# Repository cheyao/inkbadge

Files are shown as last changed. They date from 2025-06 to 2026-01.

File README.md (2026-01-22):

# Undercity + Github badges

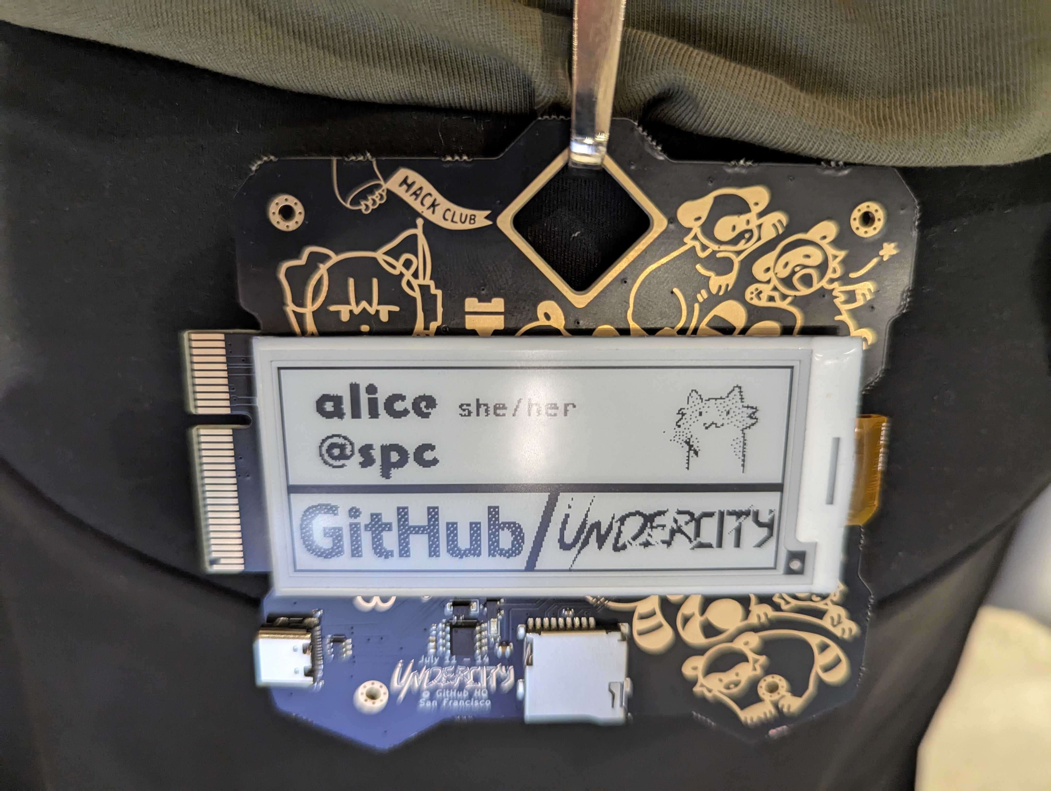
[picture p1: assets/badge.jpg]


Official badges for undercity (Hackathon @ Github HQ, https://highway.hackclub.com/)

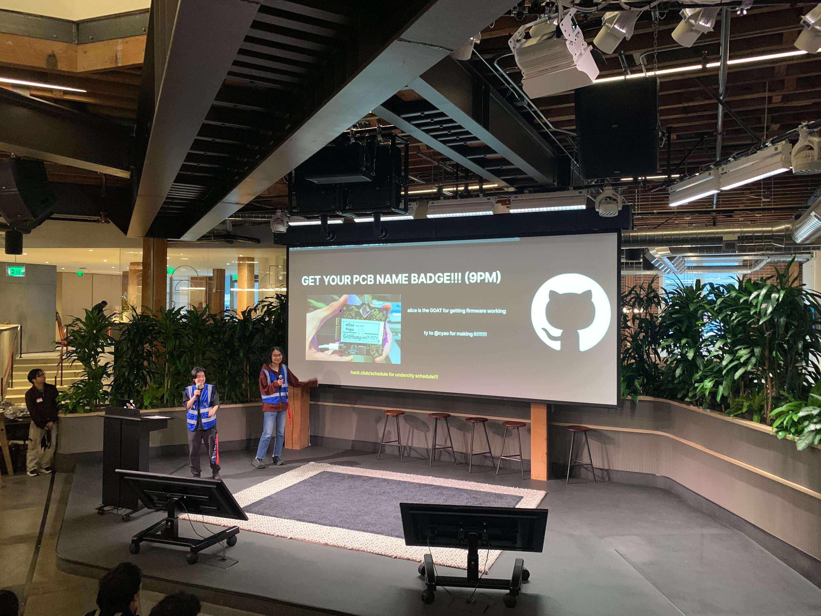
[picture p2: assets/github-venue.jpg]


Find the firmware [here](https://github.com/espcaa/undercity-lanyard)! (Start made by me, finished by spc & mpk :D)

Specs:
- 4x User buttons
- RP2350A
- Big big flash
- Super cool pcie connector
- Working firmware 
- Onboard eink module
- 6 neopixels go flash flash
- Pretty art by bnuuuuyguy!
- Awesome artline by acon (@acornitum)
- Check out pcb online [here](https://kicanvas.org/?github=https%3A%2F%2Fgithub.com%2Fcheyao%2Finkbadge%2Ftree%2Fmain%2Fhardware%2Finkbadge)

Additional battery mode avaliable! (Explosions not included this time)

Solder a lipo onto the central holes on top of the buttons - left is V+ right is GND

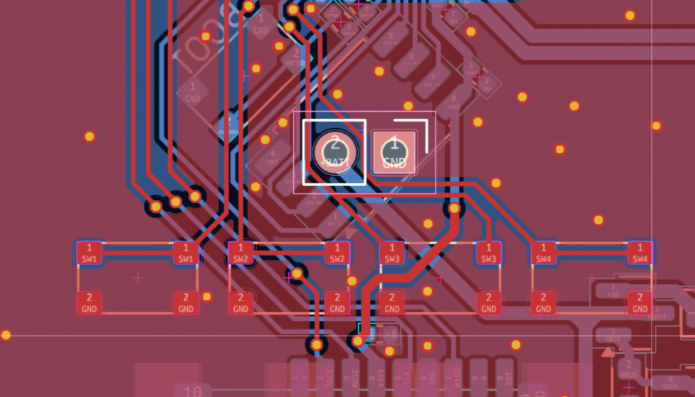
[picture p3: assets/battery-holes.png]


Licensed under Solderpad license

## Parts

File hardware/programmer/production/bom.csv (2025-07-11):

Designator | Footprint | Quantity | Value | LCSC Part #
C1, C19, C5 | 0603 | 3 | 10u | C19702
C10, C6, C7 | 0402 | 3 | 4.7u | C23733
C11, C12, C13, C14, C15, C16, C17, C18, C2, C8 | 0402 | 10 | 100n | C1525
C3, C4 | 0402 | 2 | 15p | C1548
C40 | 0402 | 1 | 4.7uF | C23733
J1 | SDCardlcsc | 1 | Micro_SD_Card | C5454948
J2 | USB_C_Receptacle_GCT_USB4105-xx-A_16P_TopMnt_Horizontal | 1 | USB_C_Receptacle_USB2.0_14P | C2765186
J3 | PCIe_x4_Edgeboard_Connector | 1 | Bus_PCI_Express_x4 | C2832353
L1 | L_pol_2016 | 1 | 3.3u | C42411119
R1 | 0402 | 1 | 10k | C25744
R16 | 0402 | 1 | 33 | C25105
R2, R4, R6 | 0402 | 3 | 1k | C11702
R3, R5 | 0402 | 2 | 5.1k | C25905
R7, R8 | 0402 | 2 | 27 | C25105
SW1, SW2 | SW_Push_SPST_TSA016 | 2 | SW_Push | C2888430
U1 | QFN-60-1EP_7x7mm_P0.4mm_EP3.4x3.4mm_ThermalVias | 1 | ~ | C42411118
U2 | SOT-223-3_TabPin2 | 1 | NCP1117-3.3_SOT223 | C6186
U3 | SOT-23-6 | 1 | SRV05-4 | C85364
U5 | SOIC-8_5.3x5.3mm_P1.27mm | 1 | W25Q128JVS | C97521
Y1 | Crystal_SMD_3225-4Pin_3.2x2.5mm | 1 | 12MHz 10pf | C20625731

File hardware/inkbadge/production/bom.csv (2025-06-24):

Designator | Footprint | Quantity | Value | LCSC Part #
C1, C19, C28, C5, C9 | 0603 | 5 | 10uF | C19702
C10, C6, C7 | 0402 | 3 | 4.7uF | C23733
C11, C12, C13, C14, C15, C16, C17, C18, C2, C22, C32, C33, C34, C35, C36, C8 | 0402 | 16 | 100nF | C1525
C20, C21, C23, C24, C25, C26, C30, C31, C37, C38 | 0402 | 10 | 1uF | C52923
C27, C29, C39 | 0603 | 3 | 4.7uF | C69335
C3, C4 | 0402 | 2 | 15pF | C1548
C40 | 0402 | 1 | 4.7uF | C1548
D1, D11, D2, D3 | D_SOD-123 | 4 | MBR0530 | C5204746
D10, D5, D6, D7, D8, D9 | LED_WS2812B-2020_PLCC4_2.0x2.0mm | 6 | WS2812B-2020 | C5349955
D4 | 0603 | 1 | LED | C2286
J1 | SDCardlcsc | 1 | Micro_SD_Card | C5454948
J3 | USB_C_Receptacle_GCT_USB4105-xx-A_16P_TopMnt_Horizontal | 1 | USB_C_Receptacle_USB2.0_14P | C2765186
L1 | L_pol_2016 | 1 | 3.3u | C42411119
L2 | L_APV_ANR4018 | 1 | 10uH 1A | C167808
Q2 | SOT-23 | 1 | AO3401A | C15127
Q3 | SOT-23 | 1 | IRLML2060 | C5122027
R1, R13 | 0402 | 2 | 10k | C25744
R10, R14 | 0402 | 2 | 1.5k | C25867
R11, R15 | 0402 | 2 | 470 | C25117
R12 | 0402 | 1 | 0.47 | C3017627
R16 | 0402 | 1 | 33 | C25105
R2, R4, R6 | 0402 | 3 | 1k | C11702
R3, R5, R9 | 0402 | 3 | 5.1k | C25905
R7, R8 | 0402 | 2 | 27 | C25105
SW1, SW2, SW3, SW4, SW5, SW6 | SW_Push_SPST_TSA016 | 6 | SW_Push | C2888430
U1 | QFN-60-1EP_7x7mm_P0.4mm_EP3.4x3.4mm_ThermalVias | 1 | RP2350A | C42411118
U2 | SOT-223-3_TabPin2 | 1 | NCP1117-3.3_SOT223 | C6186
U3 | SOT-23-6 | 1 | SRV05-4 | C85364
U4 | LCSC_1x24-1MP_P0.5mm_Horizontal | 1 | Conn | C262567
U5 | SOIC-8_5.3x5.3mm_P1.27mm | 1 | W25Q128JVS | C97521
U6 | SOP-8_3.9x4.9mm_P1.27mm-TP | 1 | TP4056-42-ESOP8 | C16581
Y1 | Crystal_SMD_3225-4Pin_3.2x2.5mm | 1 | 12MHz 10pf | C20625731

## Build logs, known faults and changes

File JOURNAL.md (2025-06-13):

# 30/05/25

Copied the base rp2350a schematic, and decided on the screen:



https://item.taobao.com/item.htm?id=673989348784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{%22aplus_abtest%22%3A%22d8240614a409935e88e0eb0ca016da3a%22}&xxc=taobaoSearch

- 1.5h

----------

# 31/05/25

Made a basic connector pinout, chinese stuff got bad docs lol.



- 1.5h

----------

Yay after some searching I found an adafruit example schematic:



- 1h

----------

Finished most of the schematic!!!



- 1h

----------

# 01/06/25

Layed out the connector side of the PCB! acon ghosted me tho :skulk: 



- 0.5h

----------

# 03/06/25

And here's the current progress!



- 1h

----------

# 05/06/25

Forgot to journal yesterday, but this is what I got today

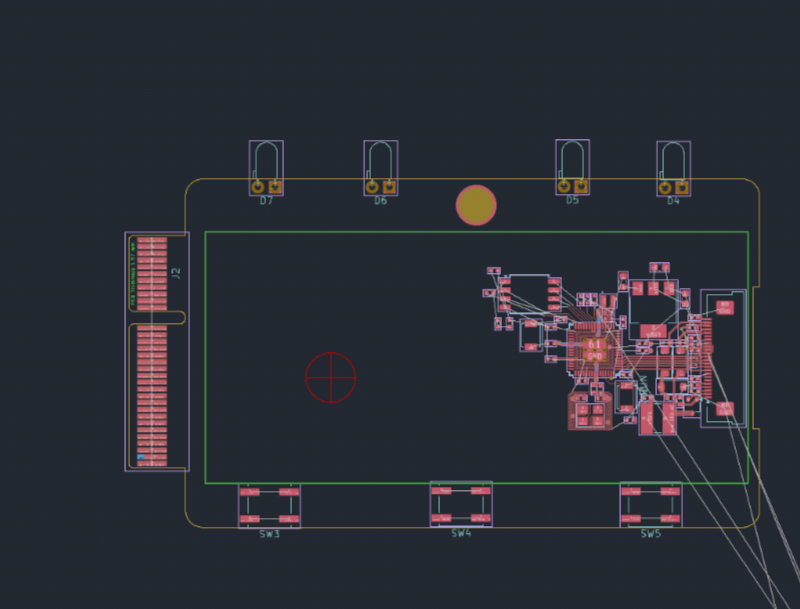
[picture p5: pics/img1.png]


- 1h

----------

# 06/06/25

Made the rough outline w/acon, looks pretty good!

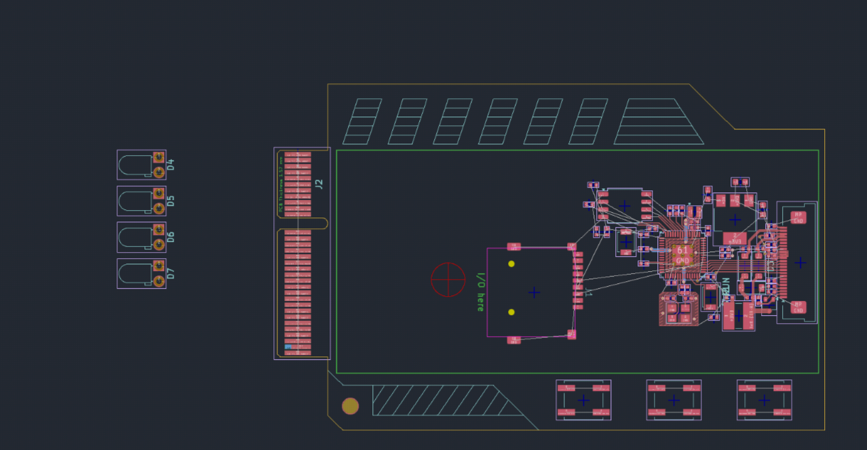
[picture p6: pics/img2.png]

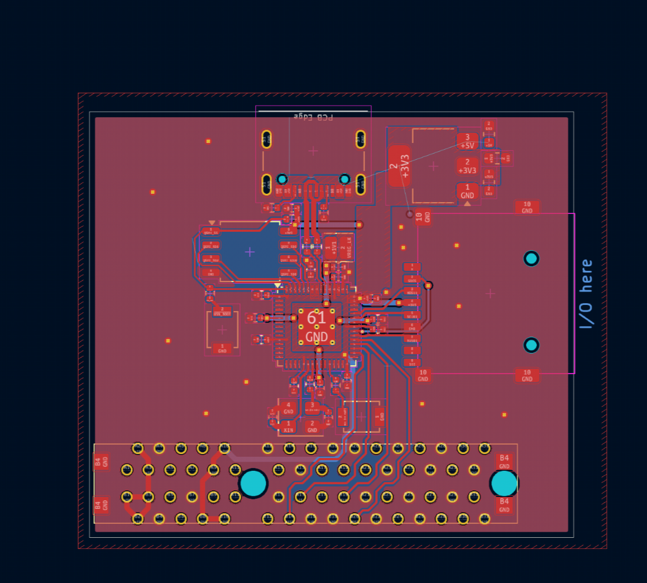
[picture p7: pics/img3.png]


- 1.5h

----------

# 08-09/06/25

And the programmer is done!

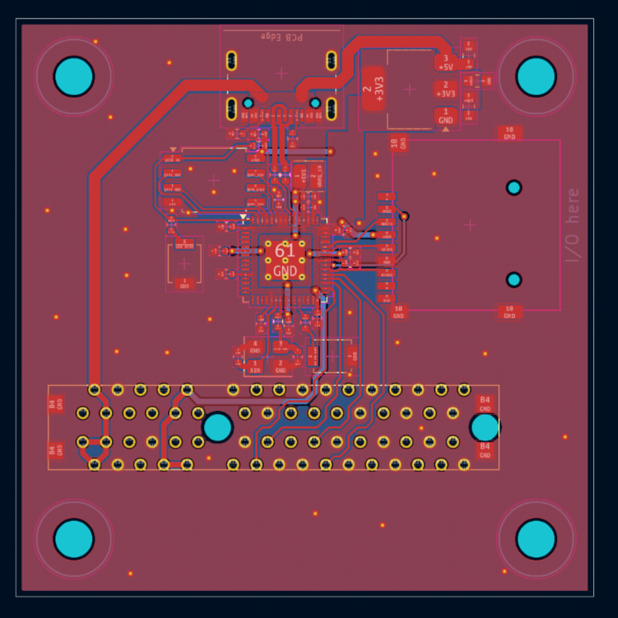
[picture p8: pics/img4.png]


- 4h

----------

# 11/06/25

Finished the programmer!

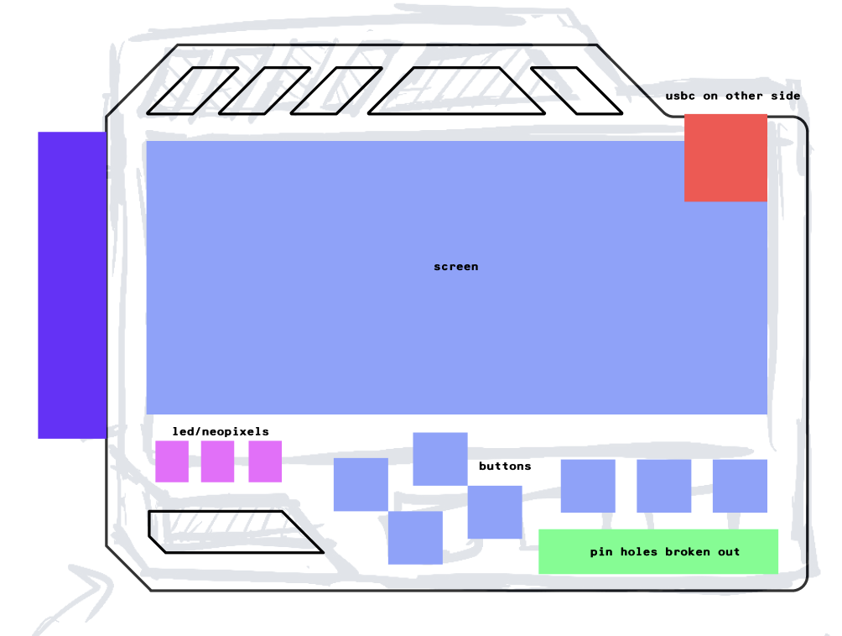
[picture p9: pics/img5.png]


- 1h

----------

# 13/06/25

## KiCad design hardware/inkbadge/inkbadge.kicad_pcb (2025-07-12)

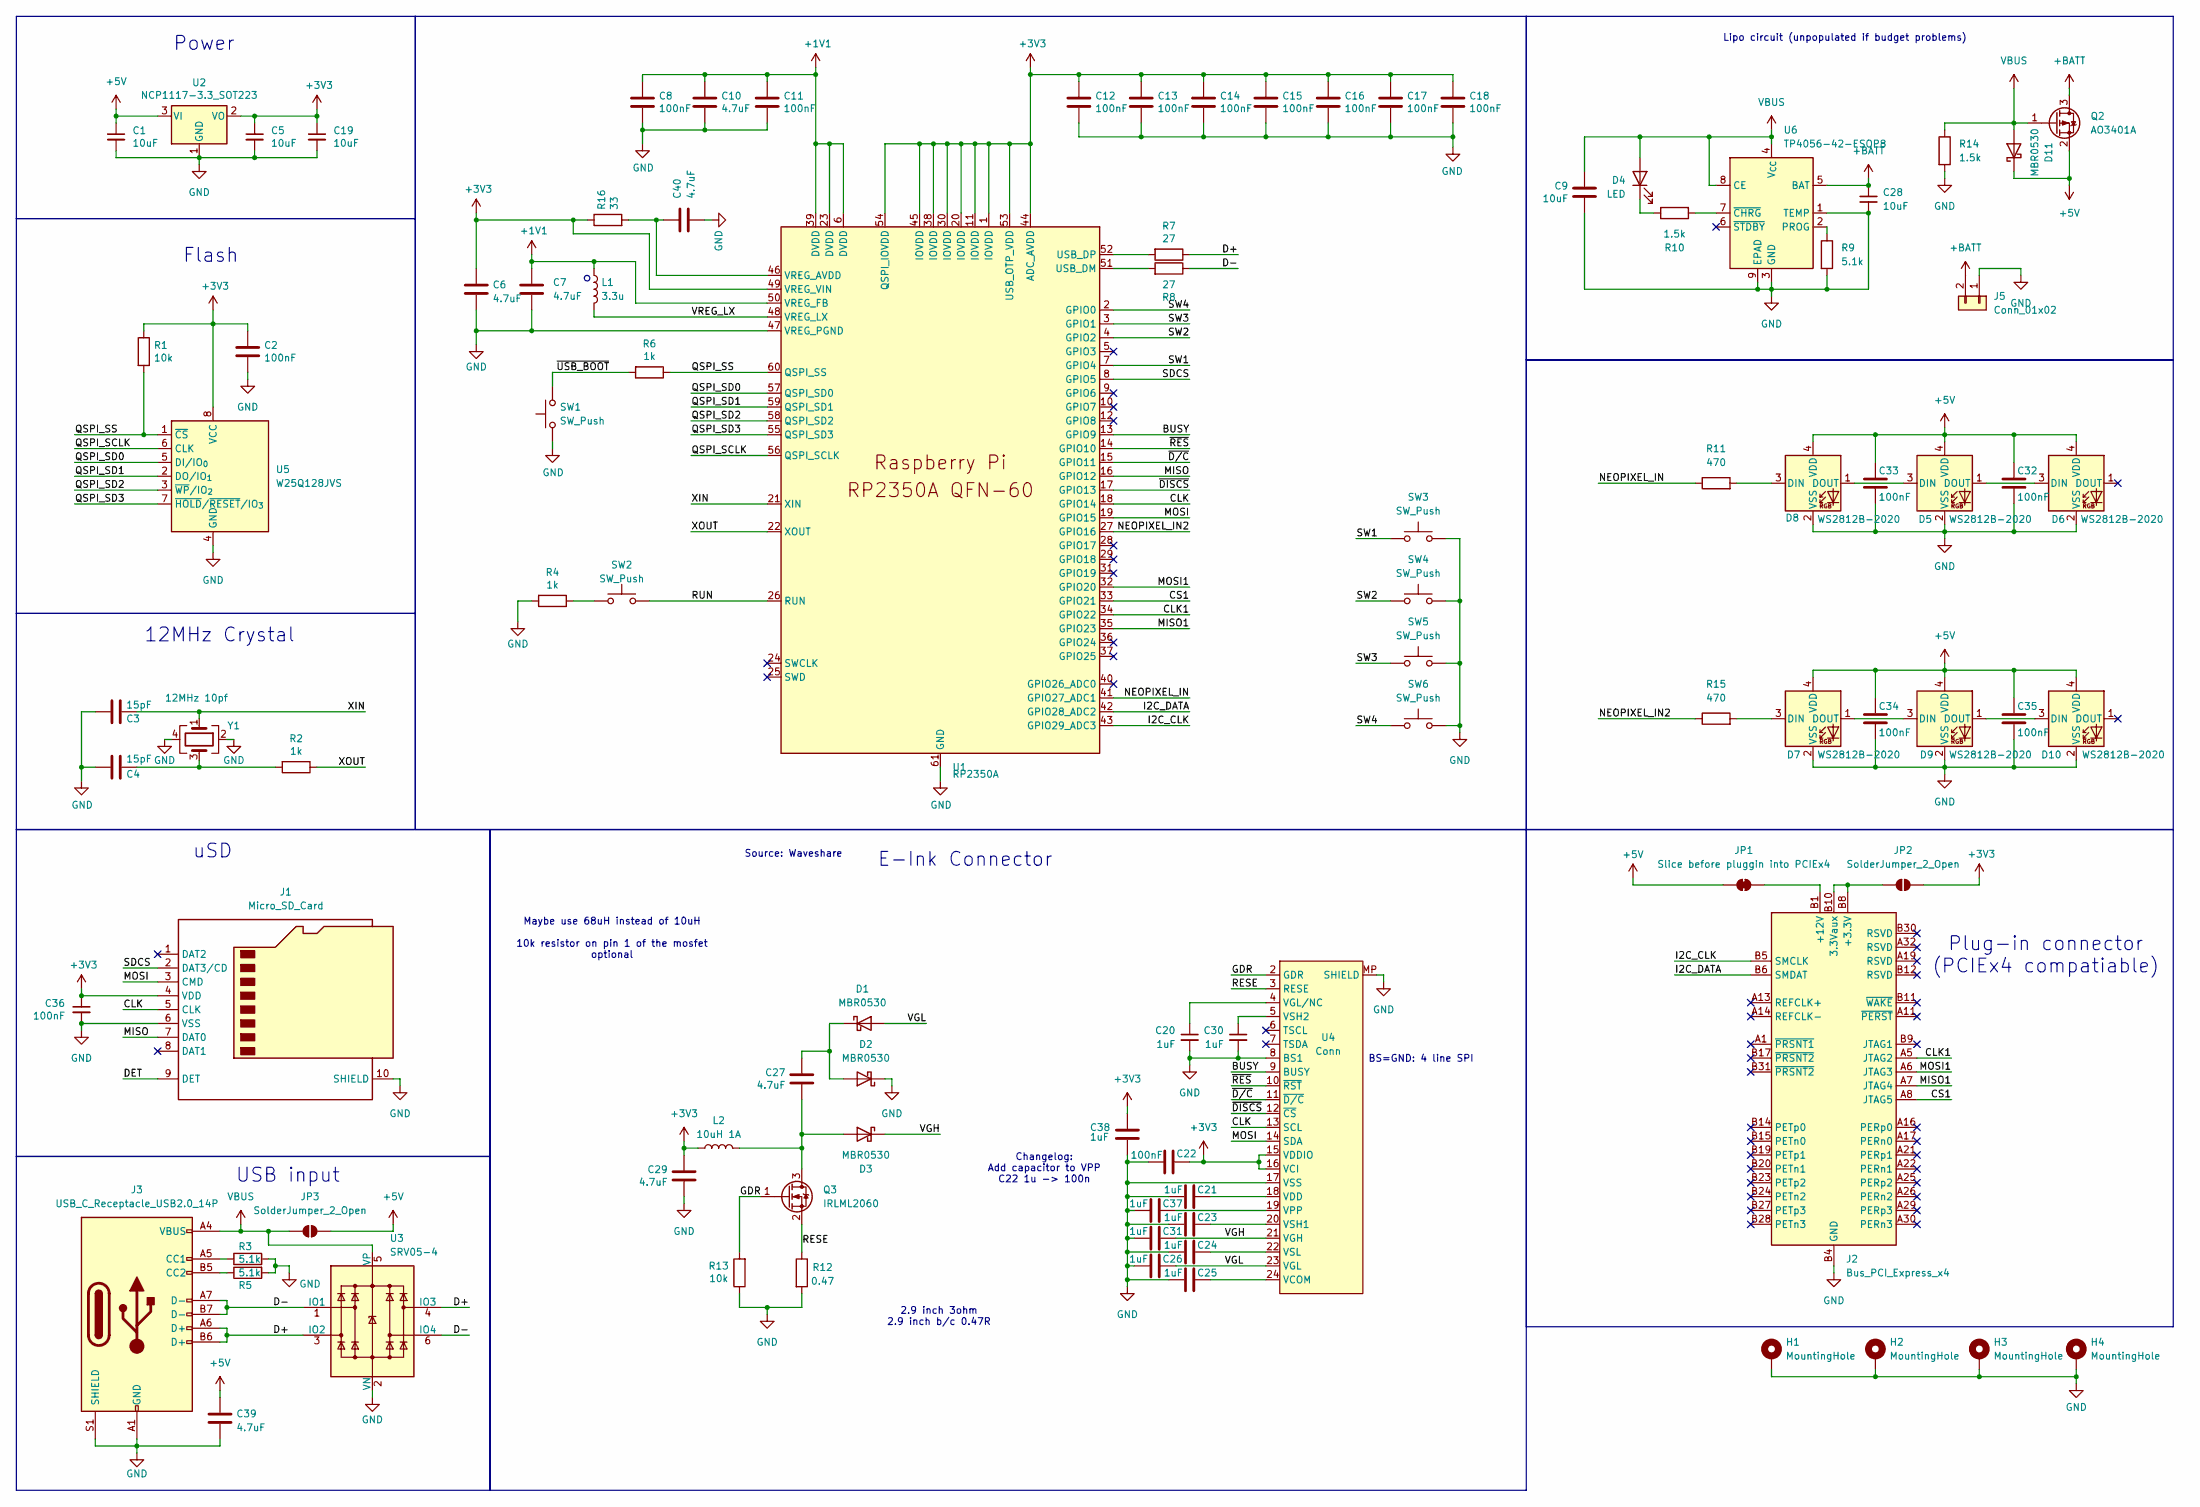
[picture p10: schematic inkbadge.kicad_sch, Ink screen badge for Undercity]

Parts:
C1, C5, C9, C19, C28: 10uF; C_0603_1608Metric; LCSC Part # C19702
C2, C8, C11, C12, C13, C14, C15, C16, C17, C18, C22, C32, C33, C34, C35, C36: 100nF; C_0402_1005Metric; LCSC Part # C1525
C3, C4: 15pF; C_0402_1005Metric; LCSC Part # C1548
C6, C7, C10, C40: 4.7uF; C_0402_1005Metric; LCSC Part # C23733
C20, C21, C23, C24, C25, C26, C30, C31, C37, C38: 1uF; C_0402_1005Metric; LCSC Part # C52923
C27, C29, C39: 4.7uF; C_0603_1608Metric; LCSC Part # C69335
D1, D2, D3, D11: MBR0530; D_SOD-123; LCSC Part # C5204746
D4: LED; LED_0603_1608Metric; LCSC Part # C2286
D5, D6, D7, D8, D9, D10: WS2812B-2020; LED_WS2812B-2020_PLCC4_2.0x2.0mm; LCSC Part # C5349955
H1, H2, H3, H4: MountingHole; MountingHole_2.2mm_M2_Pad_Via
J1: Micro_SD_Card; SDCardlcsc; LCSC Part # C5454948
J2: Bus_PCI_Express_x4; BUS_PCIexpress_x4
J3: USB_C_Receptacle_USB2.0_14P; USB_C_Receptacle_GCT_USB4105-xx-A_16P_TopMnt_Horizontal; LCSC Part # C2765186
J5: Conn_01x02; PinHeader_1x02_P2.54mm_Vertical
JP1: Slice before pluggin into PCIEx4; SolderJumper-2_P1.3mm_Bridged_RoundedPad1.0x1.5mm
JP2, JP3: SolderJumper_2_Open; SolderJumper-2_P1.3mm_Open_RoundedPad1.0x1.5mm
L1: 3.3u; L_pol_2016; LCSC Part # C42411119
L2: 10uH 1A; L_APV_ANR4018; LCSC Part # C167808
Q2: AO3401A; SOT-23; LCSC Part # C15127
Q3: IRLML2060; SOT-23; LCSC Part # C5122027
R1, R13: 10k; R_0402_1005Metric; LCSC Part # C25744
R2, R4, R6: 1k; R_0402_1005Metric; LCSC Part # C11702
R3, R5, R9: 5.1k; R_0402_1005Metric; LCSC Part # C25905
R7, R8: 27; R_0402_1005Metric; LCSC Part # C25105
R10, R14: 1.5k; R_0402_1005Metric; LCSC Part # C25867
R11, R15: 470; R_0402_1005Metric; LCSC Part # C25117
R12: 0.47; R_0402_1005Metric; LCSC Part # C3017627
R16: 33; R_0402_1005Metric; LCSC Part # C25105
SW1, SW2, SW3, SW4, SW5, SW6: SW_Push; SW_Push_SPST_TSA016; LCSC Part # C2888430
U1: RP2350A; QFN-60-1EP_7x7mm_P0.4mm_EP3.4x3.4mm_ThermalVias; LCSC Part # C42411118
U2: NCP1117-3.3_SOT223; SOT-223-3_TabPin2; LCSC Part # C6186
U3: SRV05-4; SOT-23-6; LCSC Part # C85364
U4: Conn; LCSC_1x24-1MP_P0.5mm_Horizontal; LCSC Part # C262567
U5: W25Q128JVS; SOIC-8_5.3x5.3mm_P1.27mm; LCSC Part # C97521
U6: TP4056-42-ESOP8; SOP-8_3.9x4.9mm_P1.27mm-TP; LCSC Part # C16581
Y1: 12MHz 10pf; Crystal_SMD_3225-4Pin_3.2x2.5mm; LCSC Part # C20625731

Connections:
+1V1: C7.1, C8.1, C10.1, C11.1, L1.1, U1.6 (DVDD), U1.23 (DVDD), U1.39 (DVDD), U1.50 (VREG_FB)
+3V3: C2.1, C5.1, C6.1, C12.1, C13.1, C14.1, C15.1, C16.1, C17.1, C18.1, C19.1, C22.1, C29.1, C36.1, C38.1, J1.4 (VDD), JP2.2 (B), L2.1, R1.1, R16.1, U1.1 (IOVDD), U1.11 (IOVDD), U1.20 (IOVDD), U1.30 (IOVDD), U1.38 (IOVDD), U1.44 (ADC_AVDD), U1.45 (IOVDD), U1.49 (VREG_VIN), U1.53 (USB_OTP_VDD), U1.54 (QSPI_IOVDD), U2.2 (VO), U4.15 (VDDIO), U4.16 (VCI), U5.8 (VCC)
+5V: C1.1, C32.1, C33.1, C34.1, C35.1, C39.1, D5.4 (VDD), D6.4 (VDD), D7.4 (VDD), D8.4 (VDD), D9.4 (VDD), D10.4 (VDD), D11.1 (K), JP1.1 (A), JP3.2 (B), Q2.2 (S), U2.3 (VI)
+BATT: C28.1, J5.2, Q2.3 (D), U6.5 (BAT)
/BUSY: U1.13 (GPIO9), U4.9 (BUSY)
/CLK: J1.5 (CLK), U1.18 (GPIO14), U4.13 (SCL)
/CLK1: J2.A5 (JTAG2), U1.34 (GPIO22)
/CS1: J2.A8 (JTAG5), U1.33 (GPIO21)
/D+: J3.A6 (D+), J3.B6 (D+), R7.1, U3.3 (IO2), U3.4 (IO3)
/D-: J3.A7 (D-), J3.B7 (D-), R8.1, U3.1 (IO1), U3.6 (IO4)
/DET: J1.9 (DET)
/GDR: Q3.1 (G), R13.2, U4.2 (GDR)
/I2C_CLK: J2.B5 (SMCLK), U1.43 (GPIO29_ADC3)
/I2C_DATA: J2.B6 (SMDAT), U1.42 (GPIO28_ADC2)
/MISO: J1.7 (DAT0), U1.16 (GPIO12)
/MISO1: J2.A7 (JTAG4), U1.35 (GPIO23)
/MOSI: J1.3 (CMD), U1.19 (GPIO15), U4.14 (SDA)
/MOSI1: J2.A6 (JTAG3), U1.32 (GPIO20)
/NEOPIXEL_IN: R11.1, U1.41 (GPIO27_ADC1)
/NEOPIXEL_IN2: R15.1, U1.27 (GPIO16)
/QSPI_SCLK: U1.56 (QSPI_SCLK), U5.6 (CLK)
/QSPI_SD0: U1.57 (QSPI_SD0), U5.5 (DI/IO_{0})
/QSPI_SD1: U1.59 (QSPI_SD1), U5.2 (DO/IO_{1})
/QSPI_SD2: U1.58 (QSPI_SD2), U5.3 (~WP/IO_{2})
/QSPI_SD3: U1.55 (QSPI_SD3), U5.7 (~HOLD/~RESET/IO_{3})
/QSPI_SS: R1.2, R6.1, U1.60 (QSPI_SS), U5.1 (~CS)
/RESE: Q3.2 (S), R12.1, U4.3 (RESE)
/RUN: SW2.2, U1.26 (RUN)
/SDCS: J1.2 (DAT3/CD), U1.8 (GPIO5)
/SW1: SW3.1, U1.7 (GPIO4)
/SW2: SW4.1, U1.4 (GPIO2)
/SW3: SW5.1, U1.3 (GPIO1)
/SW4: SW6.1, U1.2 (GPIO0)
/VGH: C31.1, D3.1 (K), U4.21 (VGH)
/VGL: C26.1, D1.2 (A), U4.23 (VGL)
/VREG_LX: L1.2, U1.48 (VREG_LX)
/XIN: C3.1, U1.21 (XIN), Y1.1
/XOUT: R2.1, U1.22 (XOUT)
/~DISCS: U1.17 (GPIO13), U4.12 (~CS)
/~D/C: U1.15 (GPIO11), U4.11 (~D/C)
/~RES: U1.14 (GPIO10), U4.10 (~RST)
/~USB_BOOT: R6.2, SW1.2
GND: C1.2, C2.2, C3.2, C4.2, C5.2, C6.2, C7.2, C8.2, C9.2, C10.2, C11.2, C12.2, C13.2, C14.2, C15.2, C16.2, C17.2, C18.2, C19.2, C20.2, C21.2, C22.2, C23.2, C24.2, C25.2, C26.2, C28.2, C29.2, C30.2, C31.2, C32.2, C33.2, C34.2, C35.2, C36.2, C37.2, C38.2, C39.2, C40.2, D2.1 (K), D5.2 (VSS), D6.2 (VSS), D7.2 (VSS), D8.2 (VSS), D9.2 (VSS), D10.2 (VSS), H1.1, H2.1, H3.1, H4.1, J1.6 (VSS), J1.10 (SHIELD), J2.A4 (GND), J2.A12 (GND), J2.A15 (GND), J2.A18 (GND), J2.A20 (GND), J2.A23 (GND), J2.A24 (GND), J2.A27 (GND), J2.A28 (GND), J2.A31 (GND), J2.B4 (GND), J2.B7 (GND), J2.B13 (GND), J2.B16 (GND), J2.B18 (GND), J2.B21 (GND), J2.B22 (GND), J2.B25 (GND), J2.B26 (GND), J2.B29 (GND), J2.B32 (GND), J3.A1 (GND), J3.A12 (GND), J3.B1 (GND), J3.B12 (GND), J3.S1 (SHIELD), J5.1, R3.2, R4.2, R5.2, R9.2, R12.2, R13.1, R14.2, SW1.1, SW3.2, SW4.2, SW5.2, SW6.2, U1.47 (VREG_PGND), U1.61 (GND), U2.1 (GND), U3.2 (VN), U4.8 (BS1), U4.17 (VSS), U4.MP (SHIELD), U5.4 (GND), U6.1 (TEMP), U6.3 (GND), U6.9 (EPAD), Y1.2, Y1.4
unnamed: C4.1, R2.2, Y1.3
unnamed: C27.1, D1.1 (K), D2.2 (A)
unnamed: C27.2, D3.2 (A), L2.2, Q3.3 (D)
unnamed: D4.1 (K), R10.1
unnamed: D5.3 (DIN), D8.1 (DOUT)
unnamed: D5.1 (DOUT), D6.3 (DIN)
unnamed: D7.3 (DIN), R15.2
unnamed: D7.1 (DOUT), D9.3 (DIN)
unnamed: D8.3 (DIN), R11.2
unnamed: D9.1 (DOUT), D10.3 (DIN)
unnamed: J2.A9 (+3.3V), J2.A10 (+3.3V), J2.B8 (+3.3V), J2.B10 (3.3Vaux), JP2.1 (A)
unnamed: J3.A5 (CC1), R3.1
unnamed: J3.B5 (CC2), R5.1
unnamed: J2.A2 (+12V), J2.A3 (+12V), J2.B1 (+12V), J2.B2 (+12V), J2.B3 (+12V), JP1.2 (B)
unnamed: R4.1, SW2.1
unnamed: R8.2, U1.51 (USB_DM)
unnamed: R7.2, U1.52 (USB_DP)
unnamed: C40.1, R16.2, U1.46 (VREG_AVDD)
unnamed: C25.1, U4.24 (VCOM)
unnamed: C21.1, U4.18 (VDD)
unnamed: C20.1, U4.4 (VGL/NC)
unnamed: C37.1, U4.19 (VPP)
unnamed: C23.1, U4.20 (VSH1)
unnamed: C30.1, U4.5 (VSH2)
unnamed: C24.1, U4.22 (VSL)
unnamed: R9.1, U6.2 (PROG)
unnamed: R10.2, U6.7 (~CHRG)
VBUS: C9.1, D4.2 (A), D11.2 (A), J3.A4 (VBUS), J3.A9 (VBUS), J3.B4 (VBUS), J3.B9 (VBUS), JP3.1 (A), Q2.1 (G), R14.1, U3.5 (VP), U6.4 (V_{CC}), U6.8 (CE)

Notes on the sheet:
USB input
Maybe use 68uH instead of 10uH 10k resistor on pin 1 of the mosfet optional
Plug-in connector (PCIEx4 compatiable)
Changelog: Add capacitor to VPP C22 1u -> 100n
Lipo circuit (unpopulated if budget problems)
Flash
2.9 inch 3ohm 2.9 inch b/c 0.47R
BS=GND: 4 line SPI
uSD
Source: Waveshare
12MHz Crystal
Power
E-Ink Connector

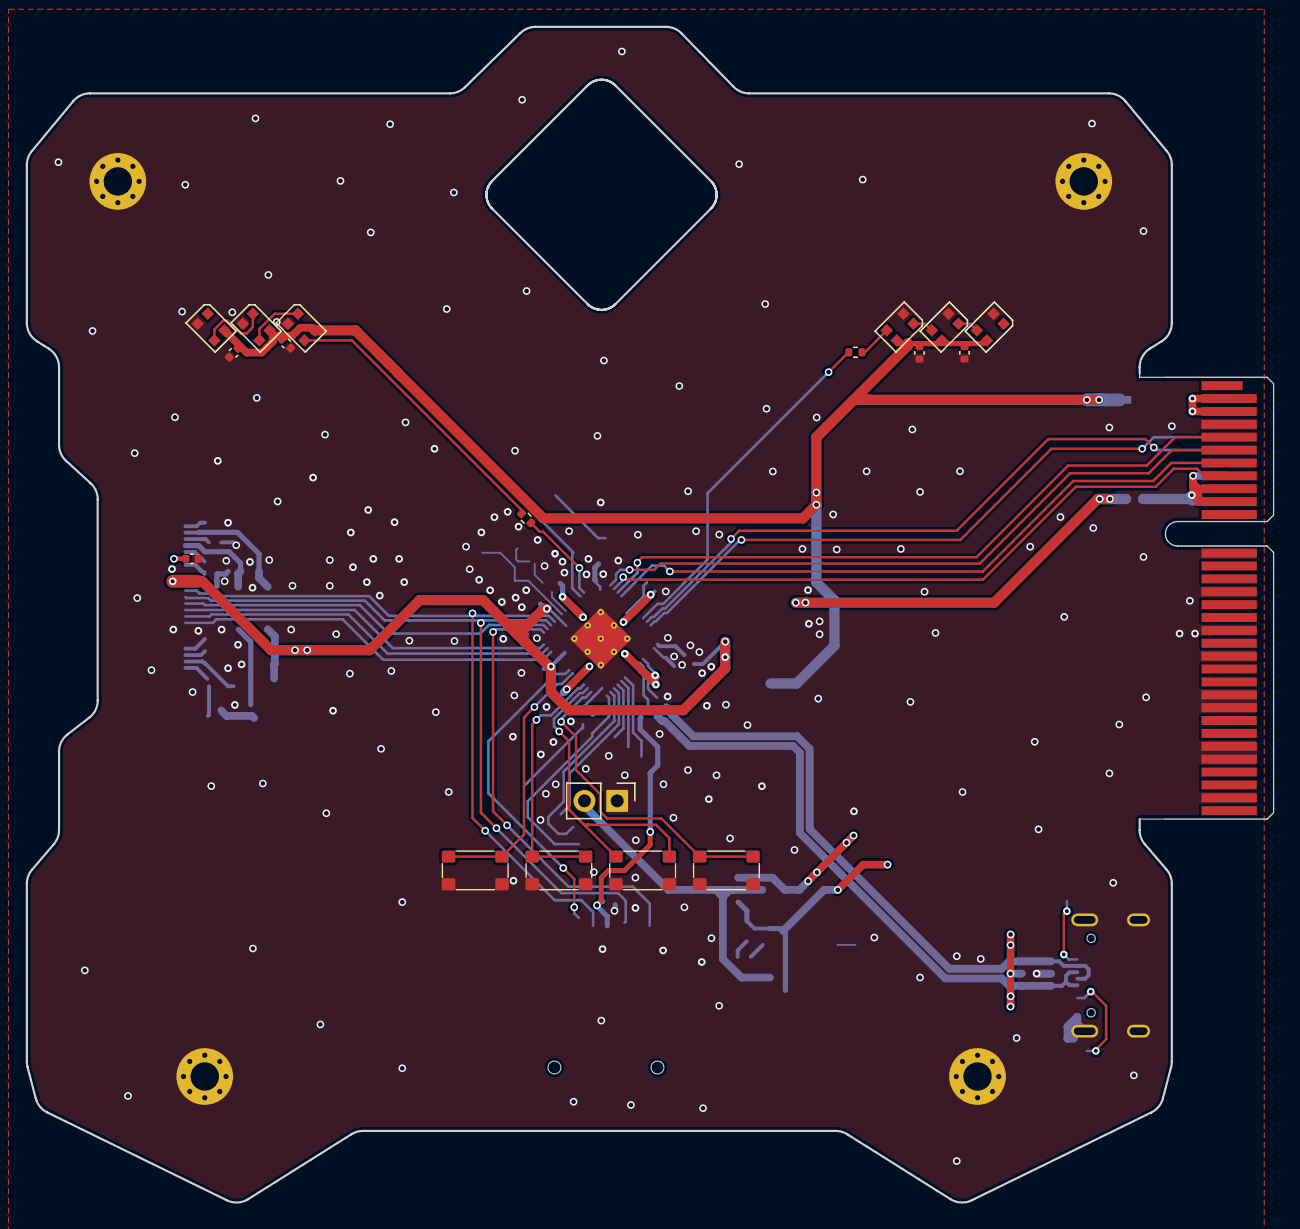
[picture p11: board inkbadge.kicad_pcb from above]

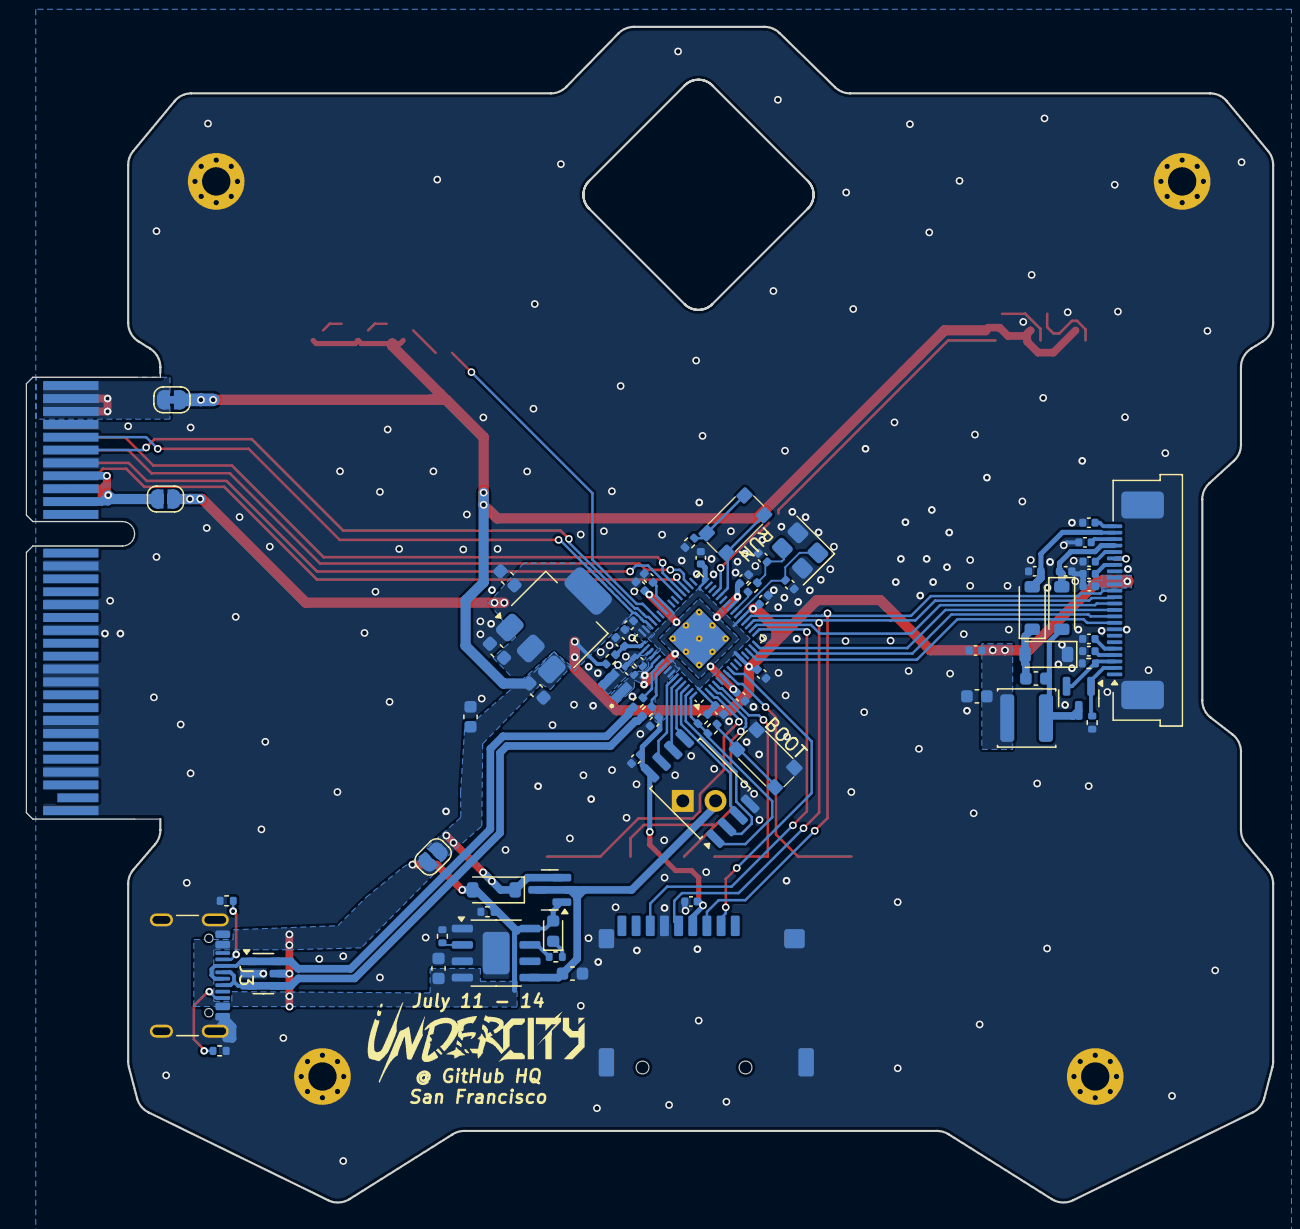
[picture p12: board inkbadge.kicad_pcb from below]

Board: 2 copper layers, 96.8 x 91.3 mm, 95 parts (73 on the bottom side), 70 nets.

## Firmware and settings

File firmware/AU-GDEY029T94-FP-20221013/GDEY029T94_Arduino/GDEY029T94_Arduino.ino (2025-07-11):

#include <SPI.h>
#include"Ap_29demo.h"
//IO settings
int BUSY_Pin = 9; 
int RES_Pin = 10; 
int DC_Pin = 11; 
int CS_Pin = 13; 

#define EPD_W21_CS_0 digitalWrite(CS_Pin,LOW)
#define EPD_W21_CS_1 digitalWrite(CS_Pin,HIGH)
#define EPD_W21_DC_0  digitalWrite(DC_Pin,LOW)
#define EPD_W21_DC_1  digitalWrite(DC_Pin,HIGH)
#define EPD_W21_RST_0 digitalWrite(RES_Pin,LOW)
#define EPD_W21_RST_1 digitalWrite(RES_Pin,HIGH)
#define isEPD_W21_BUSY digitalRead(BUSY_Pin)

////////FUNCTION//////
   
void SPI_Write(unsigned char value);
void Epaper_Write_Command(unsigned char command);
void Epaper_Write_Data(unsigned char command);
//EPD
void Epaper_HW_SW_RESET(void);
void EPD_HW_Init(void); //Electronic paper initialization
void EPD_Update(void);

void EPD_Part_Init(void);//Local refresh initialization
void EPD_Part_Update(void); 

void EPD_WhiteScreen_White(void);
void EPD_DeepSleep(void);
//Display 
void EPD_WhiteScreen_ALL(const unsigned char *datas);
void EPD_SetRAMValue_BaseMap(const unsigned char * datas);
void EPD_Dis_Part(unsigned int x_start,unsigned int y_start,const unsigned char * datas,unsigned int PART_COLUMN,unsigned int PART_LINE);
void EPD_Dis_Part_myself(unsigned int x_startA,unsigned int y_startA,const unsigned char * datasA,
                         unsigned int x_startB,unsigned int y_startB,const unsigned char * datasB,
                         unsigned int x_startC,unsigned int y_startC,const unsigned char * datasC,
                         unsigned int x_startD,unsigned int y_startD,const unsigned char * datasD,
                         unsigned int x_startE,unsigned int y_startE,const unsigned char * datasE,
                         unsigned int PART_COLUMN,unsigned int PART_LINE
                        );
void EPD_HW_Init_Fast(void);
void EPD_WhiteScreen_ALL_Fast(const unsigned char *datas);
//Display canvas function
void EPD_HW_Init_GUI(void); //EPD init GUI
void EPD_Display(unsigned char *Image); 
void EPD_HW_Init_P(void);
void EPD_Standby(void);

void EPD_HW_Init_Fast(void);
void EPD_WhiteScreen_ALL_Fast(const unsigned char *datas);
constexpr const int _MISO_EPD = 12;  // AKA SPI RX (same as SD MISO)

SPISettings spisettings(1000000, MSBFIRST, SPI_MODE0);
constexpr const int _MOSI_EPD = 15;  // AKA SPI TX (same as SD MOSI)
constexpr const int _CS_EPD = 13;
constexpr const int _SCK_EPD = 14;   // AKA SPI SCK (same as SD SCK)
void setup() {
  SPI1.setMISO(_MISO_EPD);
  SPI1.setMOSI(_MOSI_EPD);
  SPI1.setSCK(_SCK_EPD);
  SPI1.setCS(_CS_EPD);
   pinMode(BUSY_Pin, INPUT); 
   pinMode(RES_Pin, OUTPUT);  
   pinMode(DC_Pin, OUTPUT);    
   pinMode(CS_Pin, OUTPUT);   
   //SPI
   SPI1.beginTransaction(SPISettings(10000000, MSBFIRST, SPI_MODE0)); 
   SPI1.begin ();  
}
////////Partial refresh schematic////////////////

/////Y/// (0,0)               /---/(x,y)
          //                 /---/
          //                /---/  
          //x
          //
          //
//Tips//
/*When the electronic paper is refreshed in full screen, the picture flicker is a normal phenomenon, and the main function is to clear the display afterimage in the previous picture.
  When the local refresh is performed, the screen does not flash.*/
/*When you need to transplant the driver, you only need to change the corresponding IO. The BUSY pin is the input mode and the others are the output mode. */
  
void loop() {
    unsigned char fen_L,fen_H,miao_L,miao_H; 

    /************Fast picture display(1.5s)*******************/
    EPD_HW_Init_Fast(); //EPD init Fast
    EPD_WhiteScreen_ALL_Fast(gImage_1);//EPD_picture1
    EPD_DeepSleep();//EPD_DeepSleep,Sleep instruction is necessary, please do not delete!!!
    delay(2000); //2s  
    
    while(1); 
  ////////////////////////////////////////////////////////////////////////  
      //Clean
    // Clear:
    // delay(2000);
    // EPD_HW_Init();//Electronic paper initialization
    // EPD_WhiteScreen_White();  //Show all white
   //  EPD_DeepSleep();  //Enter deep sleep,Sleep instruction is necessary, please do not delete!!!
}












///////////////////EXTERNAL FUNCTION////////////////////////////////////////////////////////////////////////

//////////////////////SPI///////////////////////////////////

void SPI_Write(unsigned char value)                                    
{                                                           
  SPI1.transfer(value);
}

void Epaper_Write_Command(unsigned char command)
{
  EPD_W21_CS_0;                   
  EPD_W21_DC_0;   // command write
  SPI_Write(command);
  EPD_W21_CS_1;
}
void Epaper_Write_Data(unsigned char command)
{
  EPD_W21_CS_0;                   
  EPD_W21_DC_1;   // command write
  SPI_Write(command);
  EPD_W21_CS_1;
}

/////////////////EPD settings Functions/////////////////////
//////////////////////////////////////////////////////////////////////////////////////////////////
void EPD_HW_Init(void)
{
  EPD_W21_RST_0;  // Module reset   
  delay(10);//At least 10ms delay 
  EPD_W21_RST_1;
  delay(10); //At least 10ms delay 
  
  Epaper_READBUSY();   
  Epaper_Write_Command(0x12);  //SWRESET
  Epaper_READBUSY();   
    
  Epaper_Write_Command(0x01); //Driver output control      
  Epaper_Write_Data(0x27);
  Epaper_Write_Data(0x01);
  Epaper_Write_Data(0x00);

  Epaper_Write_Command(0x11); //data entry mode       
  Epaper_Write_Data(0x01);

  Epaper_Write_Command(0x44); //set Ram-X address start/end position   
  Epaper_Write_Data(0x00);
  Epaper_Write_Data(0x0F);    //0x0F-->(15+1)*8=128

  Epaper_Write_Command(0x45); //set Ram-Y address start/end position          
  Epaper_Write_Data(0x27);   //0x0127-->(295+1)=296
  Epaper_Write_Data(0x01);
  Epaper_Write_Data(0x00);
  Epaper_Write_Data(0x00); 

  Epaper_Write_Command(0x3C); //BorderWavefrom
  Epaper_Write_Data(0x05);  
      
  Epaper_Write_Command(0x21); //  Display update control
  Epaper_Write_Data(0x00);    
  Epaper_Write_Data(0x80);          
      
  Epaper_Write_Command(0x18); //Read built-in temperature sensor
  Epaper_Write_Data(0x80);  

  Epaper_Write_Command(0x4E);   // set RAM x address count to 0;
  Epaper_Write_Data(0x00);
  Epaper_Write_Command(0x4F);   // set RAM y address count to 0X199;    
  Epaper_Write_Data(0x27);
  Epaper_Write_Data(0x01);
  Epaper_READBUSY();
  
}
void EPD_HW_Init_Fast(void)
{
  EPD_W21_RST_0;  // Module reset   
  delay(10);//At least 10ms delay 
  EPD_W21_RST_1;
  delay(10); //At least 10ms delay 
  
  Epaper_Write_Command(0x12);  //SWRESET
  Epaper_READBUSY();   
  
  Epaper_Write_Command(0x18); //Read built-in temperature sensor
  Epaper_Write_Data(0x80);  
      
  Epaper_Write_Command(0x22); // Load temperature value
  Epaper_Write_Data(0xB1);    
  Epaper_Write_Command(0x20); 
  Epaper_READBUSY();   

  Epaper_Write_Command(0x1A); // Write to temperature register
  Epaper_Write_Data(0x64);    
  Epaper_Write_Data(0x00);  
            
  Epaper_Write_Command(0x22); // Load temperature value
  Epaper_Write_Data(0x91);    
  Epaper_Write_Command(0x20); 
  Epaper_READBUSY();   
}

/////////////////////////////////////////////////////////////////////////////////////////
void EPD_Update(void)
{   
  Epaper_Write_Command(0x22); //Display Update Control
  Epaper_Write_Data(0xF7);   
  Epaper_Write_Command(0x20); //Activate Display Update Sequence
  Epaper_READBUSY();  

}
void EPD_Update_Fast(void)
{   
  Epaper_Write_Command(0x22); //Display Update Control
  Epaper_Write_Data(0xC7);   
  Epaper_Write_Command(0x20); //Activate Display Update Sequence
  Epaper_READBUSY();   

}
void EPD_Part_Update(void)
{
  Epaper_Write_Command(0x22);//Display Update Control 
  Epaper_Write_Data(0xFF);   
  Epaper_Write_Command(0x20); //Activate Display Update Sequence
  Epaper_READBUSY();      
}
void EPD_DeepSleep(void)
{  
  Epaper_Write_Command(0x10); //enter deep sleep
  Epaper_Write_Data(0x01); 
  delay(100);
}
void Epaper_READBUSY(void)
{ 
  while(1)
  {   //=1 BUSY
     if(isEPD_W21_BUSY==0) break;
  }  
}
//////////////////////////////All screen update////////////////////////////////////////////
void EPD_WhiteScreen_ALL(const unsigned char * datas)
{
   unsigned int i;
    Epaper_Write_Command(0x24);   //write RAM for black(0)/white (1)
   for(i=0;i<4736;i++)
   {               
     Epaper_Write_Data(pgm_read_byte(&datas[i]));
   }
   EPD_Update();   
}
void EPD_WhiteScreen_ALL_Fast(const unsigned char *datas)
{
   unsigned int i;  
  Epaper_Write_Command(0x24);   //write RAM for black(0)/white (1)
   for(i=0;i<4736;i++)
   {               
      Epaper_Write_Data(pgm_read_byte(&datas[i]));
   } 
   
   EPD_Update_Fast();  
}
///////////////////////////Part update//////////////////////////////////////////////
void EPD_SetRAMValue_BaseMap( const unsigned char * datas)
{
  unsigned int i;   
  const unsigned char  *datas_flag;   
  datas_flag=datas;
  Epaper_Write_Command(0x24);   //Write Black and White image to RAM
   for(i=0;i<4736;i++)
   {               
     Epaper_Write_Data(pgm_read_byte(&datas[i]));
   }
   datas=datas_flag;
  Epaper_Write_Command(0x26);   //Write Black and White image to RAM
   for(i=0;i<4736;i++)
   {               
     Epaper_Write_Data(pgm_read_byte(&datas[i]));
   }
   EPD_Update();   
}


void EPD_Dis_Part(unsigned int x_start,unsigned int y_start,const unsigned char * datas,unsigned int PART_COLUMN,unsigned int PART_LINE)
{
  unsigned int i;  
  unsigned int x_end,y_start1,y_start2,y_end1,y_end2;
  x_start=x_start/8;//
  x_end=x_start+PART_LINE/8-1; 
  
  y_start1=0;
  y_start2=y_start;
  if(y_start>=256)
  {
    y_start1=y_start2/256;
    y_start2=y_start2%256;
  }
  y_end1=0;
  y_end2=y_start+PART_COLUMN-1;
  if(y_end2>=256)
  {
    y_end1=y_end2/256;
    y_end2=y_end2%256;    
  }   
  // Add hardware reset to prevent background color change
  EPD_W21_RST_0;  // Module reset   
  delay(10);//At least 10ms delay 
  EPD_W21_RST_1;
  delay(10); //At least 10ms delay 
  
  //Lock the border to prevent flashing
  Epaper_Write_Command(0x3C); //BorderWavefrom,
  Epaper_Write_Data(0x80); 
  //  
  Epaper_Write_Command(0x44);       // set RAM x address start/end, in page 35
  Epaper_Write_Data(x_start);    // RAM x address start at 00h;
  Epaper_Write_Data(x_end);    // RAM x address end at 0fh(15+1)*8->128 
  Epaper_Write_Command(0x45);       // set RAM y address start/end, in page 35
  Epaper_Write_Data(y_start2);    // RAM y address start at 0127h;
  Epaper_Write_Data(y_start1);    // RAM y address start at 0127h;
  Epaper_Write_Data(y_end2);    // RAM y address end at 00h;
  Epaper_Write_Data(y_end1);    // ????=0 


  Epaper_Write_Command(0x4E);   // set RAM x address count to 0;
  Epaper_Write_Data(x_start); 
  Epaper_Write_Command(0x4F);   // set RAM y address count to 0X127;    
  Epaper_Write_Data(y_start2);
  Epaper_Write_Data(y_start1);
  
  
   Epaper_Write_Command(0x24);   //Write Black and White image to RAM
   for(i=0;i<PART_COLUMN*PART_LINE/8;i++)
   {                         
     Epaper_Write_Data(pgm_read_byte(&datas[i]));
   } 
   EPD_Part_Update();

}
////////////////////////////////////TIME///////////////////////////////////////////////////
void EPD_Dis_Part_myself(unsigned int x_startA,unsigned int y_startA,const unsigned char * datasA,
                         unsigned int x_startB,unsigned int y_startB,const unsigned char * datasB,
                         unsigned int x_startC,unsigned int y_startC,const unsigned char * datasC,
                         unsigned int x_startD,unsigned int y_startD,const unsigned char * datasD,
                         unsigned int x_startE,unsigned int y_startE,const unsigned char * datasE,
                         unsigned int PART_COLUMN,unsigned int PART_LINE
                        )
{
  unsigned int i;  
  unsigned int x_end,y_start1,y_start2,y_end1,y_end2;
  
  //Data A////////////////////////////
  x_startA=x_startA/8;//Convert to byte
  x_end=x_startA+PART_LINE/8-1; 
  
  y_start1=0;
  y_start2=y_startA-1;
  if(y_startA>=256)
  {
    y_start1=y_start2/256;
    y_start2=y_start2%256;
  }
  y_end1=0;
  y_end2=y_startA+PART_COLUMN-1;
  if(y_end2>=256)
  {
    y_end1=y_end2/256;
    y_end2=y_end2%256;    
  }   
  //Reset
  EPD_W21_RST_0;  // Module reset   
  delay(10);//At least 10ms delay 
  EPD_W21_RST_1;
  delay(10); //At least 10ms delay 
    
  Epaper_Write_Command(0x3C); //BorderWavefrom
  Epaper_Write_Data(0x80);  
//
  Epaper_Write_Command(0x44);       // set RAM x address start/end, in page 35
  Epaper_Write_Data(x_startA);    // RAM x address start at 00h;
  Epaper_Write_Data(x_end);    // RAM x address end at 0fh(15+1)*8->128 
  Epaper_Write_Command(0x45);       // set RAM y address start/end, in page 35
  Epaper_Write_Data(y_start2);    // RAM y address start at 0127h;
  Epaper_Write_Data(y_start1);    // RAM y address start at 0127h;
  Epaper_Write_Data(y_end2);    // RAM y address end at 00h;
  Epaper_Write_Data(y_end1);    


  Epaper_Write_Command(0x4E);   // set RAM x address count to 0;
  Epaper_Write_Data(x_startA); 
  Epaper_Write_Command(0x4F);   // set RAM y address count to 0X127;    
  Epaper_Write_Data(y_start2);
  Epaper_Write_Data(y_start1);
  
  
   Epaper_Write_Command(0x24);   //Write Black and White image to RAM
   for(i=0;i<PART_COLUMN*PART_LINE/8;i++)
   {                         
     Epaper_Write_Data(pgm_read_byte(&datasA[i]));
   } 
  //Data B/////////////////////////////////////
  x_startB=x_startB/8;//Convert to byte
  x_end=x_startB+PART_LINE/8-1; 
  
  y_start1=0;
  y_start2=y_startB-1;
  if(y_startB>=256)
  {
    y_start1=y_start2/256;
    y_start2=y_start2%256;
  }
  y_end1=0;
  y_end2=y_startB+PART_COLUMN-1;
  if(y_end2>=256)
  {
    y_end1=y_end2/256;
    y_end2=y_end2%256;    
  }   
  
  Epaper_Write_Command(0x44);       // set RAM x address start/end, in page 35
  Epaper_Write_Data(x_startB);    // RAM x address start at 00h;
  Epaper_Write_Data(x_end);    // RAM x address end at 0fh(15+1)*8->128 
  Epaper_Write_Command(0x45);       // set RAM y address start/end, in page 35
  Epaper_Write_Data(y_start2);    // RAM y address start at 0127h;
  Epaper_Write_Data(y_start1);    // RAM y address start at 0127h;
  Epaper_Write_Data(y_end2);    // RAM y address end at 00h;
  Epaper_Write_Data(y_end1);   


  Epaper_Write_Command(0x4E);   // set RAM x address count to 0;
  Epaper_Write_Data(x_startB); 
  Epaper_Write_Command(0x4F);   // set RAM y address count to 0X127;    
  Epaper_Write_Data(y_start2);
  Epaper_Write_Data(y_start1);
  
  
   Epaper_Write_Command(0x24);   //Write Black and White image to RAM
   for(i=0;i<PART_COLUMN*PART_LINE/8;i++)
   {                         
     Epaper_Write_Data(pgm_read_byte(&datasB[i]));
   }   
   
  //Data C//////////////////////////////////////
  x_startC=x_startC/8;//Convert to byte
  x_end=x_startC+PART_LINE/8-1; 
  
  y_start1=0;
  y_start2=y_startC-1;
  if(y_startC>=256)
  {
    y_start1=y_start2/256;
    y_start2=y_start2%256;
  }
  y_end1=0;
  y_end2=y_startC+PART_COLUMN-1;
  if(y_end2>=256)
  {
    y_end1=y_end2/256;
    y_end2=y_end2%256;    
  }   
  
  Epaper_Write_Command(0x44);       // set RAM x address start/end, in page 35
  Epaper_Write_Data(x_startC);    // RAM x address start at 00h;
  Epaper_Write_Data(x_end);    // RAM x address end at 0fh(15+1)*8->128 
  Epaper_Write_Command(0x45);       // set RAM y address start/end, in page 35
  Epaper_Write_Data(y_start2);    // RAM y address start at 0127h;
  Epaper_Write_Data(y_start1);    // RAM y address start at 0127h;
  Epaper_Write_Data(y_end2);    // RAM y address end at 00h;
  Epaper_Write_Data(y_end1);   


  Epaper_Write_Command(0x4E);   // set RAM x address count to 0;
  Epaper_Write_Data(x_startC); 
  Epaper_Write_Command(0x4F);   // set RAM y address count to 0X127;    
  Epaper_Write_Data(y_start2);
  Epaper_Write_Data(y_start1);
  
  
   Epaper_Write_Command(0x24);   //Write Black and White image to RAM
   for(i=0;i<PART_COLUMN*PART_LINE/8;i++)
   {                         
     Epaper_Write_Data(pgm_read_byte(&datasC[i]));
   }    
   
  //Data D//////////////////////////////////////
  x_startD=x_startD/8;//Convert to byte
  x_end=x_startD+PART_LINE/8-1; 
  
  y_start1=0;
  y_start2=y_startD-1;
  if(y_startD>=256)
  {
    y_start1=y_start2/256;
    y_start2=y_start2%256;
  }
  y_end1=0;
  y_end2=y_startD+PART_COLUMN-1;
  if(y_end2>=256)
  {
    y_end1=y_end2/256;
    y_end2=y_end2%256;    
  }   
  
  Epaper_Write_Command(0x44);       // set RAM x address start/end, in page 35
  Epaper_Write_Data(x_startD);    // RAM x address start at 00h;
  Epaper_Write_Data(x_end);        // RAM x address end at 0fh(15+1)*8->128 
  Epaper_Write_Command(0x45);       // set RAM y address start/end, in page 35
  Epaper_Write_Data(y_start2);    // RAM y address start at 0127h;
  Epaper_Write_Data(y_start1);    // RAM y address start at 0127h;
  Epaper_Write_Data(y_end2);    // RAM y address end at 00h;
  Epaper_Write_Data(y_end1);    


  Epaper_Write_Command(0x4E);   // set RAM x address count to 0;
  Epaper_Write_Data(x_startD); 
  Epaper_Write_Command(0x4F);   // set RAM y address count to 0X127;    
  Epaper_Write_Data(y_start2);
  Epaper_Write_Data(y_start1);
  
  
   Epaper_Write_Command(0x24);   //Write Black and White image to RAM
   for(i=0;i<PART_COLUMN*PART_LINE/8;i++)
   {                         
     Epaper_Write_Data(pgm_read_byte(&datasD[i]));
   } 
  //Data E//////////////////////////////////////
  x_startE=x_startE/8;//Convert to byte
  x_end=x_startE+PART_LINE/8-1; 
  
  y_start1=0;
  y_start2=y_startE-1;
  if(y_startE>=256)
  {
    y_start1=y_start2/256;
    y_start2=y_start2%256;
  }
  y_end1=0;
  y_end2=y_startE+PART_COLUMN-1;
  if(y_end2>=256)
  {
    y_end1=y_end2/256;
    y_end2=y_end2%256;    
  }   
  
  Epaper_Write_Command(0x44);       // set RAM x address start/end, in page 35
  Epaper_Write_Data(x_startE);    // RAM x address start at 00h;
  Epaper_Write_Data(x_end);    // RAM x address end at 0fh(15+1)*8->128 
  Epaper_Write_Command(0x45);       // set RAM y address start/end, in page 35
  Epaper_Write_Data(y_start2);    // RAM y address start at 0127h;
  Epaper_Write_Data(y_start1);    // RAM y address start at 0127h;
  Epaper_Write_Data(y_end2);    // RAM y address end at 00h;
  Epaper_Write_Data(y_end1);    


  Epaper_Write_Command(0x4E);   // set RAM x address count to 0;
  Epaper_Write_Data(x_startE); 
  Epaper_Write_Command(0x4F);   // set RAM y address count to 0X127;    
  Epaper_Write_Data(y_start2);
  Epaper_Write_Data(y_start1);
  
  
   Epaper_Write_Command(0x24);   //Write Black and White image to RAM
   for(i=0;i<PART_COLUMN*PART_LINE/8;i++)
   {                         
     Epaper_Write_Data(pgm_read_byte(&datasE[i]));
   }   
   EPD_Part_Update();

}






/////////////////////////////////Single display////////////////////////////////////////////////

void EPD_WhiteScreen_Black(void)
{
   unsigned int i;
    Epaper_Write_Command(0x24);   //write RAM for black(0)/white (1)
    for(i=0;i<4736;i++)
    {
        Epaper_Write_Data(0x00);    
    }
    EPD_Update();
}

void EPD_WhiteScreen_White(void)
{
   unsigned int i;
    Epaper_Write_Command(0x24);   //write RAM for black(0)/white (1)
    for(i=0;i<4736;i++)
    {
        Epaper_Write_Data(0xff);    
    }
    EPD_Update();
}



//////////////////////////////////END//////////////////////////////////////////////////

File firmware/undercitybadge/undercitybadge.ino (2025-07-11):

/*
  Hack Club Undercity badge firmware
  Credit: 

  The circuit according to the badge schematic:
   SD card attached to SPI bus on rp2350:
   ************ SPI0 ************
   ** MISO (AKA RX) - gpio12
   ** MOSI (AKA TX) - gpio15
   ** CS            - gpio5
   ** SCK           - gpio14

  Eink Display attached to SPI bus on rp2350:
   ************ SPI0 ************
   ** MISO (AKA RX) - gpio12
   ** MOSI (AKA TX) - gpio15
   ** CS            - gpio5
   ** SCK           - gpio14

*/

/*
    *** DEPENDENCIES ***

  - arduino SPI
  - adafruit SD 
  - earlphilehower arduino-pico
  - adafruit EPD
  - adafruit ImageReader
*/

// This are GP pins for SPI on the Raspberry Pi Pico board, and connect
// to different *board* level pinouts.  Check the PCB while wiring.
// Only certain pins can be used by the SPI hardware, so if if you change
// these be sure they are legal or the program will crash.
constexpr const int _MISO_SD = 12;  // Changed to gpio12 as per schematic
constexpr const int _MOSI_SD = 15;  // Changed to gpio15 as per schematic
constexpr const int _CS_SD = 5;
constexpr const int _SCK_SD = 14;   // Changed to gpio14 as per schematic

// same as above but for display
// Eink display is sharing the SPI bus with the SD card
constexpr const int _MISO_EPD = 12;  // AKA SPI RX (same as SD MISO)
constexpr const int _MOSI_EPD = 15;  // AKA SPI TX (same as SD MOSI)
constexpr const int _CS_EPD = 13;
constexpr const int _SCK_EPD = 14;   // AKA SPI SCK (same as SD SCK)

// more disp pins
constexpr const int _BUSY_EPD = 9;
constexpr const int _DC_EPD = 11;
constexpr const int _RESET_EPD = 10;
constexpr const int _CS_SRAM = -1; // not using external sram ic

// Programma!
constexpr const int _CLK_PGM = 22;
constexpr const int _MOSI_PGM = 20;
constexpr const int _MISO_PGM = 23;
constexpr const int _CS_PGM = 21;

// Neopixels
constexpr const int NEOPIXEL_R = 27;
constexpr const int NEOPIXEL_L = 16;

// Buttons
constexpr const int BUTTON_1 = 4;
constexpr const int BUTTON_2 = 2;
constexpr const int BUTTON_3 = 1;
constexpr const int BUTTON_4 = 0;

#include <SPI.h>
#include <SPISlave.h>
#include <Adafruit_EPD.h>
#include <Adafruit_GFX.h>
#include <Adafruit_ImageReader_EPD.h>
#include <Adafruit_NeoPixel.h>

Adafruit_SSD1680 display(296, 128, _DC_EPD, _RESET_EPD, _CS_EPD, _CS_SRAM, _BUSY_EPD, &SPI);

SPISettings spisettings(1000000, MSBFIRST, SPI_MODE0);

Adafruit_NeoPixel stripl = Adafruit_NeoPixel(3, NEOPIXEL_L, NEO_GRB + NEO_KHZ800);
Adafruit_NeoPixel stripr = Adafruit_NeoPixel(3, NEOPIXEL_R, NEO_GRB + NEO_KHZ800);

void setup1() {}

void drawBMPFromMemory(const uint8_t *bmpData) {
  if (bmpData[0] != 'B' || bmpData[1] != 'M') {
    Serial.println("Not a valid BMP file");
    return;
  }

  uint32_t pixelOffset = bmpData[10] | (bmpData[11] << 8) | (bmpData[12] << 16) | (bmpData[13] << 24);
  int32_t width = bmpData[18] | (bmpData[19] << 8) | (bmpData[20] << 16) | (bmpData[21] << 24);
  int32_t height = bmpData[22] | (bmpData[23] << 8) | (bmpData[24] << 16) | (bmpData[25] << 24);
  uint16_t bpp = bmpData[28] | (bmpData[29] << 8);

  if (bpp != 24) {
    Serial.print("Unsupported BMP bit depth: ");
    Serial.println(bpp);
    return;
  }

  Serial.print("Drawing BMP from memory: ");
  Serial.print(width);
  Serial.print("x");
  Serial.println(height);

  // Each row is aligned to 4 bytes
  uint32_t rowSize = ((width * 3 + 3) / 4) * 4;

  // Draw bottom-up (BMP stores pixels from bottom row to top)
  for (int y = 0; y < height; y++) {
    for (int x = 0; x < width; x++) {
      uint32_t pixelIndex = pixelOffset + (height - 1 - y) * rowSize + x * 3;
      uint8_t b = bmpData[pixelIndex];
      uint8_t g = bmpData[pixelIndex + 1];
      uint8_t r = bmpData[pixelIndex + 2];

      // Simple brightness thresholding to black or white
      uint8_t brightness = (r + g + b) / 3;
      uint16_t color = (brightness > 128) ? EPD_WHITE : EPD_BLACK;

      display.drawPixel(x, y, color);
    }
  }
}

#include "badge.h"

String input = "";

void reDraw() {
  // NOTE: set rotation of display here, idk what the correct setting it is on the hardware
  display.setRotation(2);

  display.clearBuffer();
  display.fillScreen(EPD_WHITE);

  Serial.println("Image loaded successfully!");
  drawBMPFromMemory(badge_bmp);
  display.display();

  delay(2000);

  Serial.println("Loading name.");
  display.setTextWrap(true);
  display.setCursor(10, 10);
  display.setTextSize(2);
  display.setTextColor(EPD_BLACK);
  display.print(input);
  display.display();

  delay(2000);
}

void setup() {
  // Open serial communications and wait for port to open
  Serial.begin(115200);

  stripr.begin();
  stripr.show();

  stripl.begin();
  stripl.show();

  /*
  // Set up SPI pins for the SD card
  SPI1.setMISO(_MISO_SD);
  SPI1.setMOSI(_MOSI_SD);
  SPI1.setSCK(_SCK_SD);
  SPI1.setCS(_CS_SD);

  Serial.println("Opening display");
  display.begin();

  reDraw();

  Serial.println("Enter your name and press ENTER:");
  while (true) {
    while (Serial.available()) {
      char c = Serial.read();
      if (c == '\n' || c == '\r') {
        if (input.length() > 0) break;
      } else {
        input += c;
        Serial.print(c); // Echo back
      }
    }

    if (input.length() > 0 && (input.endsWith("\n") || input.endsWith("\r"))) {
      break;
    }

    delay(10);
  }

  input.trim(); // Remove any newline/whitespace
  Serial.print("\nSaving name: ");
  Serial.println(input);

  reDraw(); // Refresh the screen with new name
            */
}

void colorWipe(uint32_t c, uint8_t wait) {
  for(uint16_t i=0; i<stripl.numPixels(); i++) {
    stripl.setPixelColor(i, c);
    stripl.show();

    stripr.setPixelColor(i, c);
    stripr.show();

    delay(20);
  }
}

void loop() {
  // Read programmer for flashes
  /*
  if (recvBuffReady) {
    Serial.println("Loading name.");
    File32 name = SD.open("name.txt", FILE_WRITE);

    // if the file opened okay, write to it:
    if (name) {
      Serial.print("Writing to name.txt...");
      name.print(recvBuff);
      // close the file:
      name.close();
      Serial.println("Done saving name.");
    } else {
      // if the file didn't open, print an error:
      Serial.println("Error opening name.txt");
    }

    reDraw();
  }
  */

  colorWipe(stripl.Color(255, 0, 0), 50); // Red
  colorWipe(stripl.Color(0, 255, 0), 50); // Green
  colorWipe(stripl.Color(0, 0, 255), 50); // Blue

}

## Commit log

2025-06-19 Badge like done!
    [inkbadge.kicad_pcb, inkbadge.kicad_sch]
2025-06-20 Finish programmer
    [inkbadge.kicad_pcb, inkbadge.kicad_sch, programmer.kicad_pcb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]
2025-07-11 SOME FIRMWARE IG FAQ THE WORLD IDC ME DIE
    [bom.csv, designators.csv, inkbadge.kicad_pcb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]
2025-07-11 FIRMWARE IDKFHRGVKQHBJ
    [inkbadge.kicad_pcb, inkbadge.kicad_sch]
2026-01-22 Fix broken CDN links
    [inkbadge.kicad_sch]
